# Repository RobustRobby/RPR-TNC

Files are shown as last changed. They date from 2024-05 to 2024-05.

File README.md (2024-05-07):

1. Introduction
The first design of a Teensy-based TNC as a replacement for the SCS Tracker was conceived by Peter Mack and Hans-Peter Helfert, DL6MAA, of SCS. It was based on a stack of a Teensy 4.0 board on top of an audio shield, which was itself on top of a piece of generic PCB for holding some components like a PTT transistor and some LEDs. Soon however, the stack of three PCBs was found to be sub-optimal and the idea of designing a custom PCB came into existence. Peter designed a first version of such a custom PCB, but lacked the time to finish it.

2. The present design
The present design was made by Robert, DM4RW, starting from the initial design of Peter. It is made using KiCad, now in version 7 (note that earlier versions of KiCad cannot open files saved in KiCad 7 format). The idea of the design revolves around putting the SGTL5000 sound chip (the same as used on the audio shield) together will all other components required on a main PCB, no longer requiring the use of an audio shield. Also the Teensy 4.0 micro-controller board finds a place on the main PCB, slightly elevated so as to allow space for components directly under the Teensy.

3. The PCB
The PCB provides space for the SGTL5000 sound chip plus its supporting components, a GPS/GNSS module, connectors such as SMA for an antenna for GPS/GNSS and mini-DIN-6 for connecting a transceiver, signaling LEDs, a 3,5mm RST socket for auxiliary use and a push button to initiate firmware updates. In addition, the design provides for its own power supply allowing power to be provided via pin 5 of the mini-DIN-6 socket as well as PTT via separate PTT line and via the audio-out line (the latter can be activated with a jumper).

4. Specifics of the design
The GNSS module used so far is a Quectel LC76. This is not obligatory, any GPS/GNSS module having the same pin-out and having the same physical size can be used, as long as its (serial) interface to the Teensy runs with 9k6 bps. A simple power back-up arrangement was made, using an over-sized capacitor. This will not allow the GNSS module to continue to run for a long time, but it at least bridges shorter interruptions of the power supply. The LC76 automatically recognizes whether the antenna needs power or not, and deactivates power if there is something wrong the antenna line or the antenna. The Teensy uses an unshielded processor. The external antenna is therefore a requirement and should be put away from the PCB as far as possible, preferably with a free sight to the skies.

The SGTL5000 sound chip finds its place beneath the Teensy. It is the 20 (21) pin version, as opposed to the 32 pin version used on the audio shield. However, the 32 pin version has been discontinued, the 20 pin version not. Note that the chip is very small: it measures 4×4mm with 5 pins on each side, plus a 21st pin on the bottom. There is no means of soldering this by hand, a decent re-flow installation is the least you need to put it into place.

The 3,5mm RST socket is meant to support auxiliary services. As to the date of writing, no firmware supporting such services in a flawless manner has been issued. The RST socket may therefore be omitted, it does not change the behavior of the TNC in any way.

The on-board power supply accepts input voltages between 8 and 28 volts on pin 5 of the mini-DIN-6 socket, and reduces this to 5 volts for the Teensy. It is based on a step-down converter by TI, the TPS54202(H). It is important to note that this converter comes in two flavors, with the H at the end and without. The only difference is the “enable voltage”. The one needs a high voltage, the other a low. For the H version, resistor R13 must be omitted, otherwise the converter won’t start. For the flavor without the H, resistor R13 has to be on the board. Simple measures were taken to prevent current flowing in an uncontrolled manner from computer to external power supply or vice versa in case the Teensy is connected to USB AND external power. However, for that to work, the Teensy must be slightly modified in that the trace connecting the power coming from the USB to the main 5v rail on the Teensy is interrupted (see the Teensy documentation that comes with every Teensy). It is then bridged by a diode that is on the PCB. If you do not need an external power supply, all components related to the power supply can be safely omitted. In that case, powering the TNC can only be done via USB connected to the Teensy.

5. About the files
You’ll find the KiCad files which you can open with the freely available KiCad. At least version 7 should be used, or higher. But not lower, that won’t work. You’ll find Gerber files with which the PCBs can be produced. Furthermore there is a BOM (bill of materials) and P&P (pick-and-placement) files. These were generated to have the board produced by JLCPCB and in addition to that, have all SMD components soldered on the board by JLCPCB. Only the GNSS module and wired components must then be soldered in order to get a fully charged RPR TNC. However, you can choose any other service provider that does the same, although in that case you’d be surely advised to regenerate all files according to the instructions of that service provider. Also with JLCPCB it pays off to check whether their requirements have changed and if so, regenerate all files.

Robert, DM4RW (Meersburg, 07/05/2024)

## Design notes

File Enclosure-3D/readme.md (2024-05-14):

About the enclosures

These enclosures were designed by Oliver, DL4KA. You'll find two versions, one for use without a display and one for use with. The enclosures consist of various parts, notably a main body and two front panels for the rear and the back. For the version with display, there is also a transparent window, which protects the LCD screen.

You can print these items yourself or have them printed at some facility, depending on your preference.

For the enclosure without screen, you can also have alumimium front panels. These you'll find in the main directory under "covers" and are actually KiCad files. You can have these produced at some PCB producing facility that can produce PCBs made of aluminium.

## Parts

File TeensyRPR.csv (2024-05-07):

Source: | C:\Users\rober\OneDrive\Documents\KiCAD\TeensyRPRv3r3\TeensyRPR.kicad_sch
Date: | 02/12/2023 18:50:19
Tool: | Eeschema 7.0.7
Generator: | C:\Program Files\KiCad\7.0\bin\scripting\plugins/bom_csv_grouped_by_value_with_fp.py
Component Count: | 70
Ref | Qnty | Value | Cmp name | Footprint | Description | Vendor | DNP
C1 | 1 | 470uF | CP_Small-Device | Capacitor_SMD:CP_Elec_6.3x7.7
C2 | 1 | 100nF | C_Small | Capacitor_SMD:C_0402_1005Metric | Unpolarized capacitor, small symbol
C4, C7, C9 | 3 | 2µ2 | C_Small | Capacitor_SMD:C_1206_3216Metric | Unpolarized capacitor, small symbol
C5, C6, C8, C16, C18, C19 | 6 | 100n | C_Small | Capacitor_SMD:C_0402_1005Metric | Unpolarized capacitor, small symbol
C10 | 1 | 150n | C_Small | Capacitor_SMD:C_0805_2012Metric | Unpolarized capacitor, small symbol
C11, C12 | 2 | 1µ | C_Small | Capacitor_SMD:C_0805_2012Metric | Unpolarized capacitor, small symbol
C13, C23, C24 | 3 | 10n | C_Small | Capacitor_SMD:C_0402_1005Metric | Unpolarized capacitor, small symbol
C15, C17 | 2 | 10µ | C_Small | Capacitor_SMD:C_0805_2012Metric | Unpolarized capacitor, small symbol
C20, C21 | 2 | 22µ | C_Small | Capacitor_SMD:C_0603_1608Metric | Unpolarized capacitor, small symbol
C22 | 1 | 75pF | C_Small | Capacitor_SMD:C_0603_1608Metric | Unpolarized capacitor, small symbol
D1, D6, D9 | 3 | D_Schottky | D_Schottky | Diode_SMD:D_SOD-123 | Schottky diode
D2, D3 | 2 | LED_RG_ACA | LED_Dual_ACA-Device | LED_THT:LED_D3.0mm-3
D4 | 1 | LED_G | LED | LED_THT:LED_D3.0mm | Light emitting diode
D5 | 1 | LED_RB_ACA | LED_Dual_ACA-Device | LED_THT:LED_D3.0mm-3
D7, D8 | 2 | TVS_5v | TVS_SOD323-TeensyRPR | Diode_SMD:D_SOD-323
D10, D11 | 2 | 1N4148WS | 1N4148WS | Diode_SMD:D_SOD-323 | 75V 0.15A Fast switching Diode, SOD-323
J1 | 1 | AudioPlug3 | AudioPlug3-Connector | Connector_Audio:Jack_3.5mm_Switronic_ST-005-G_horizontal
J2 | 1 | Mini-DIN-6 | Mini-DIN-6 | TeensyRPR:Mini_DIN_6_TE_Connectivity | 6-pin Mini-DIN connector
J3 | 1 | Bluetooth | Conn_01x06 | Connector_PinHeader_2.54mm:PinHeader_1x06_P2.54mm_Vertical | Generic connector, single row, 01x06, script generated (kicad-library-utils/schlib/autogen/connector/)
J5 | 1 | SMA | Conn_Coaxial | Connector_Coaxial:SMA_Molex_73251-2200_Horizontal | coaxial connector (BNC, SMA, SMB, SMC, Cinch/RCA, LEMO, ...)
J6 | 1 | Display (option) | Conn_01x09 | Connector_PinHeader_2.54mm:PinHeader_1x09_P2.54mm_Vertical | Generic connector, single row, 01x09, script generated (kicad-library-utils/schlib/autogen/connector/)
L1 | 1 | 470µ | L_Small | Inductor_SMD:L_1210_3225Metric | Inductor, small symbol
L2 | 1 | 15uH | L_Core_Ferrite-Device | Inductor_SMD:L_Taiyo-Yuden_MD-3030
L3 | 1 | 56nH | L_Small | Inductor_SMD:L_0402_1005Metric | Inductor, small symbol
Q1, Q2 | 2 | 2N7002 | 2N7002 | Package_TO_SOT_SMD:SOT-23 | 0.115A Id, 60V Vds, N-Channel MOSFET, SOT-23
R1, R21 | 2 | 4k7 | R | Resistor_SMD:R_0603_1608Metric | Resistor
R2, R19 | 2 | 100 | R | Resistor_SMD:R_0603_1608Metric | Resistor
R3, R4 | 2 | 2k2 | R | Resistor_SMD:R_0603_1608Metric | Resistor
R5, R7, R9, R11, R20 | 5 | 1k | R | Resistor_SMD:R_0603_1608Metric | Resistor
R6 | 1 | 330 | R | Resistor_SMD:R_0603_1608Metric | Resistor
R8, R10 | 2 | 10k | R | Resistor_SMD:R_0603_1608Metric | Resistor
R12 | 1 | 511k | R | Resistor_SMD:R_0603_1608Metric | Resistor
R13 | 1 | 105k | R | Resistor_SMD:R_0603_1608Metric | Resistor
R14 | 1 | 49.9 | R | Resistor_SMD:R_0603_1608Metric | Resistor
R15 | 1 | 100k | R | Resistor_SMD:R_0603_1608Metric | Resistor
R16 | 1 | 13.3k | R | Resistor_SMD:R_0603_1608Metric | Resistor
R17 | 1 | 33k | R | Resistor_THT:R_Axial_DIN0204_L3.6mm_D1.6mm_P2.54mm_Vertical | Resistor
R18 | 1 | 10 | R | Resistor_SMD:R_2010_5025Metric | Resistor
SW1 | 1 | SW_Push | SW_Push | Button_Switch_THT:SW_Tactile_SPST_Angled_PTS645Vx31-2LFS | Push button switch, generic, two pins
U1 | 1 | L70-R | L70-R | RF_GPS:Quectel_L70-R | Quectel GPS Module
U2 | 1 | AP2120N-1.8TRG1 | MCP1703A-1802_SOT23-Regulator_Linear | Package_TO_SOT_SMD:SOT-23
U3 | 1 | SGTL5000XNLA3 | SGTL5000XNAA3-Audio-TeensyRPR-TeensyRPR-rescue | TeensyRPR:SGTL5000-QFN-20-1EP_3x3mm_P0.4mm_ThermalVias
U4 | 1 | Teensy4.0 | Teensy4.0-TeensyRPR | TeensyRPR:Teensy40-DIP-28_W15.24mm
U6 | 1 | TPS54202DDC | TPS54202DDC | Package_TO_SOT_SMD:SOT-23-6 | 2A, 4.5 to 28V Input, EMI Friendly integrated switch synchronous step-down regulator, pulse-skipping, SOT-23-6

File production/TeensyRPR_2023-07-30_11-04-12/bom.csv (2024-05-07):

Designator | Footprint | Quantity | Value | LCSC Part #
C1 | CP_Elec_6.3x7.7 | 1 | 470uF | C114446
C10 | 805 | 1 | 150n | C307539
C11, C12 | 805 | 2 | 1µ | C28323
C13, C23, C24 | 402 | 3 | 10n | C15195
C15, C17 | 805 | 2 | 10µ | C15850
C16, C18, C19, C5, C6, C8 | 402 | 6 | 100n | C307331
C2 | 402 | 1 | 100nF | C307331
C20, C21 | 603 | 2 | 22µ | C2991805
C22 | 603 | 1 | 75pF | C282074
C4, C7, C9 | 1206 | 3 | 2µ2 | C50254
D1, D6, D9 | D_SOD-123 | 3 | D_Schottky | C8598
D10, D11 | D_SOD-323 | 2 | 1N4148WS | C108805
D7, D8 | D_SOD-323 | 2 | TVS_5v | C170167
L1 | 1210 | 1 | 470µ | C295109
L2 | L_Taiyo-Yuden_MD-3030 | 1 | 15uH | C222856
L3 | 402 | 1 | 56nH | C27143
Q1 | SOT-23 | 1 | 2N7002 | C65189
R1 | 603 | 1 | 4k7 | C23162
R10, R8 | 603 | 2 | 10k | C23179
R11, R5, R7, R9 | 603 | 4 | 470 | C23179
R12 | 603 | 1 | 511k | C101089
R13 | 603 | 1 | 105k | C100713
R14 | 603 | 1 | 49.9 | C114625
R15 | 603 | 1 | 100k | C465461
R16 | 603 | 1 | 13.3k | C234280
R17 | 603 | 1 | 33k | C4216
R18 | 2010 | 1 | 10 | C458682
R19, R2 | 603 | 2 | 100 | C22775
R3, R4 | 603 | 2 | 2k2 | C4190
R6 | 603 | 1 | 330 | C23138
U1 | Quectel_L70-R | 1 | L70-R | C2916232
U2 | SOT-23 | 1 | AP2120N-1.8TRG1 | C460317
U3 | SGTL5000-QFN-20-1EP_3x3mm_P0.4mm_ThermalVias | 1 | SGTL5000XNLA3 | C2651833
U6 | SOT-23-6 | 1 | TPS54202DDC | C191884

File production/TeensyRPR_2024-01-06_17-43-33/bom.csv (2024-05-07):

Designator | Footprint | Quantity | Value | LCSC Part #
C1 | CP_Elec_6.3x7.7 | 1 | 470uF | C114446
C10 | 0805 | 1 | 150n | C113852
C11, C12 | 0805 | 2 | 1µ | C28323
C13, C23, C24 | 0402 | 3 | 10n | C15195
C15, C17 | 0805 | 2 | 10µ | C15850
C16, C18, C19, C2, C5, C6, C8 | 0402 | 7 | 100n | C307331
C20, C21 | 0603 | 2 | 22µ | C2992620
C22 | 0603 | 1 | 75pF | C282074
C4, C7, C9 | 1206 | 3 | 2µ2 | C50254
D1, D6, D9 | D_SOD-123 | 3 | D_Schottky | C8598
D10, D11 | D_SOD-323 | 2 | 1N4148WS | C108805
D7, D8 | D_SOD-323 | 2 | TVS_5v | C85200
L1 | 1210 | 1 | 470µ | C295109
L2 | L_Taiyo-Yuden_MD-3030 | 1 | 15uH | C222856
L3 | 0402 | 1 | 56nH | C27143
Q1, Q2 | SOT-23 | 2 | 2N7002 | C916396
R1, R21 | 0603 | 2 | 4k7 | C23162
R10, R8 | 0603 | 2 | 10k | C23179
R11, R20, R5, R7, R9 | 0603 | 5 | 1k | C2784879
R12 | 0603 | 1 | 511k | C101089
R13 | 0603 | 1 | 105k | C141685
R14 | 0603 | 1 | 49.9 | C114625
R15 | 0603 | 1 | 100k | C465461
R16 | 0603 | 1 | 13.3k | C234280
R18 | 2010 | 1 | 10 | C458682
R19, R2 | 0603 | 2 | 100 | C22775
R3, R4 | 0603 | 2 | 2k2 | C4190
R6 | 0603 | 1 | 330 | C23138
U1 | Quectel_L70-R | 1 | L70-R | C2916232
U2 | SOT-23 | 1 | AP2120N-1.8TRG1 | C460317
U3 | SGTL5000-QFN-20-1EP_3x3mm_P0.4mm_ThermalVias | 1 | SGTL5000XNLA3 | C2651833
U6 | SOT-23-6 | 1 | TPS54202DDC | C191884

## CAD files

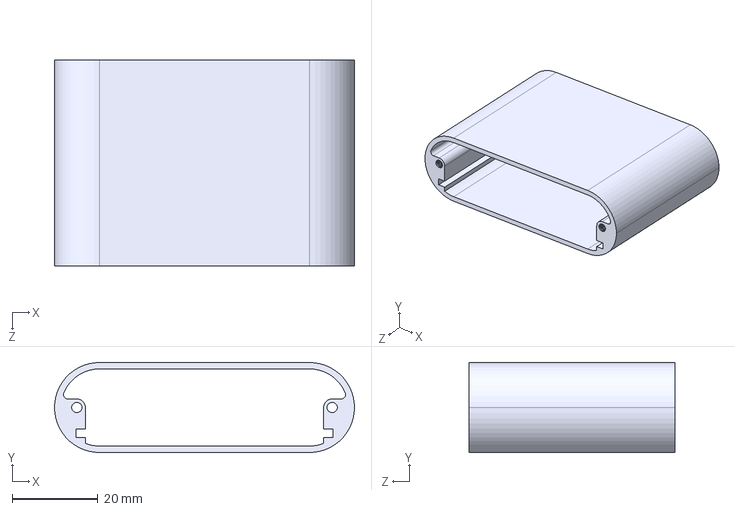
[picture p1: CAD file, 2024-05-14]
Enclosure-3D/shell.STEP
70.0 x 21.0 x 48.0 mm

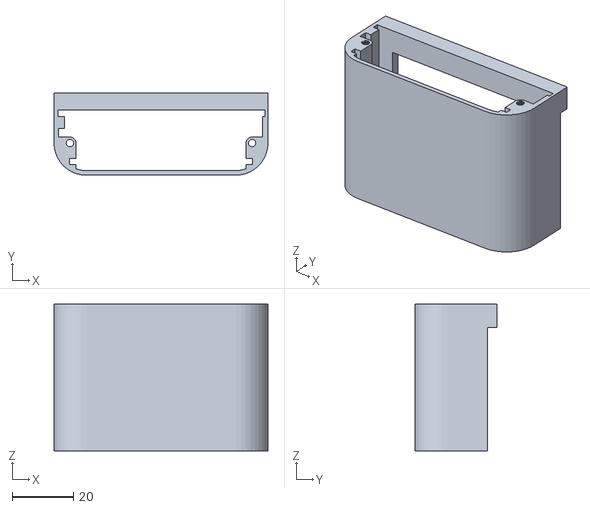
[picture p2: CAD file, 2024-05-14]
Enclosure-3D/withDisplay/shell.STL
70.0 x 27.0 x 48.0

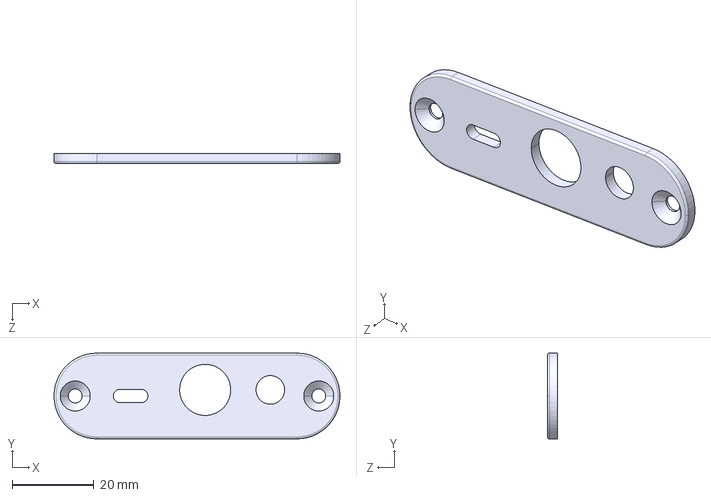
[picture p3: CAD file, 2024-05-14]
Enclosure-3D/rear_plate.STEP
70.0 x 21.0 x 2.50 mm

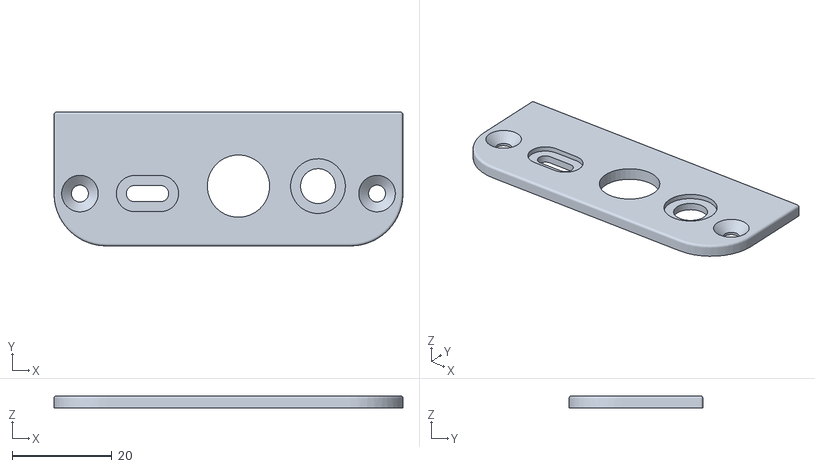
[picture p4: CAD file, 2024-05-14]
Enclosure-3D/withDisplay/rear_plate.STL
70.0 x 26.8 x 2.50

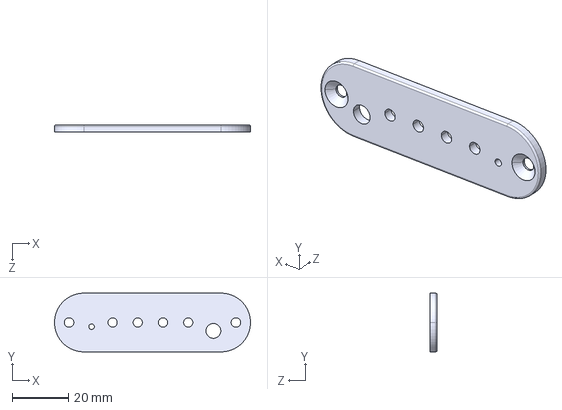
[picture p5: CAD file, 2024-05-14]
Enclosure-3D/front_plate.STEP
70.0 x 21.0 x 2.50 mm

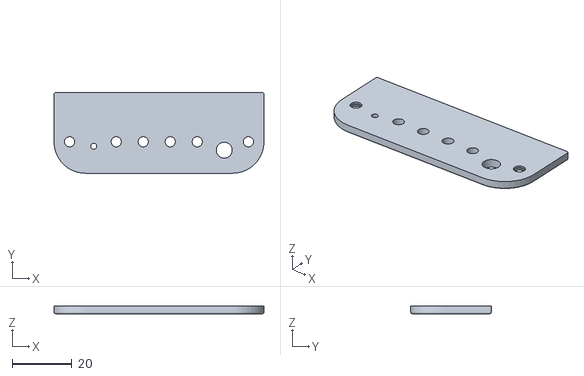
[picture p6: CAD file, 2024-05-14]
Enclosure-3D/withDisplay/front_plate.STL
70.0 x 26.8 x 2.50

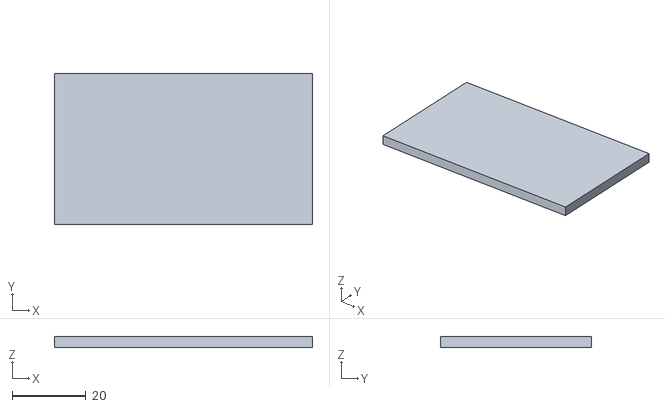
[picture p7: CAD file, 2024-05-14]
Enclosure-3D/withDisplay/PMMA-window.STL
70.0 x 41.0 x 3.00

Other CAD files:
Enclosure-3D/front_plate.STL
Enclosure-3D/rear_plate.STL
Enclosure-3D/shell.STL

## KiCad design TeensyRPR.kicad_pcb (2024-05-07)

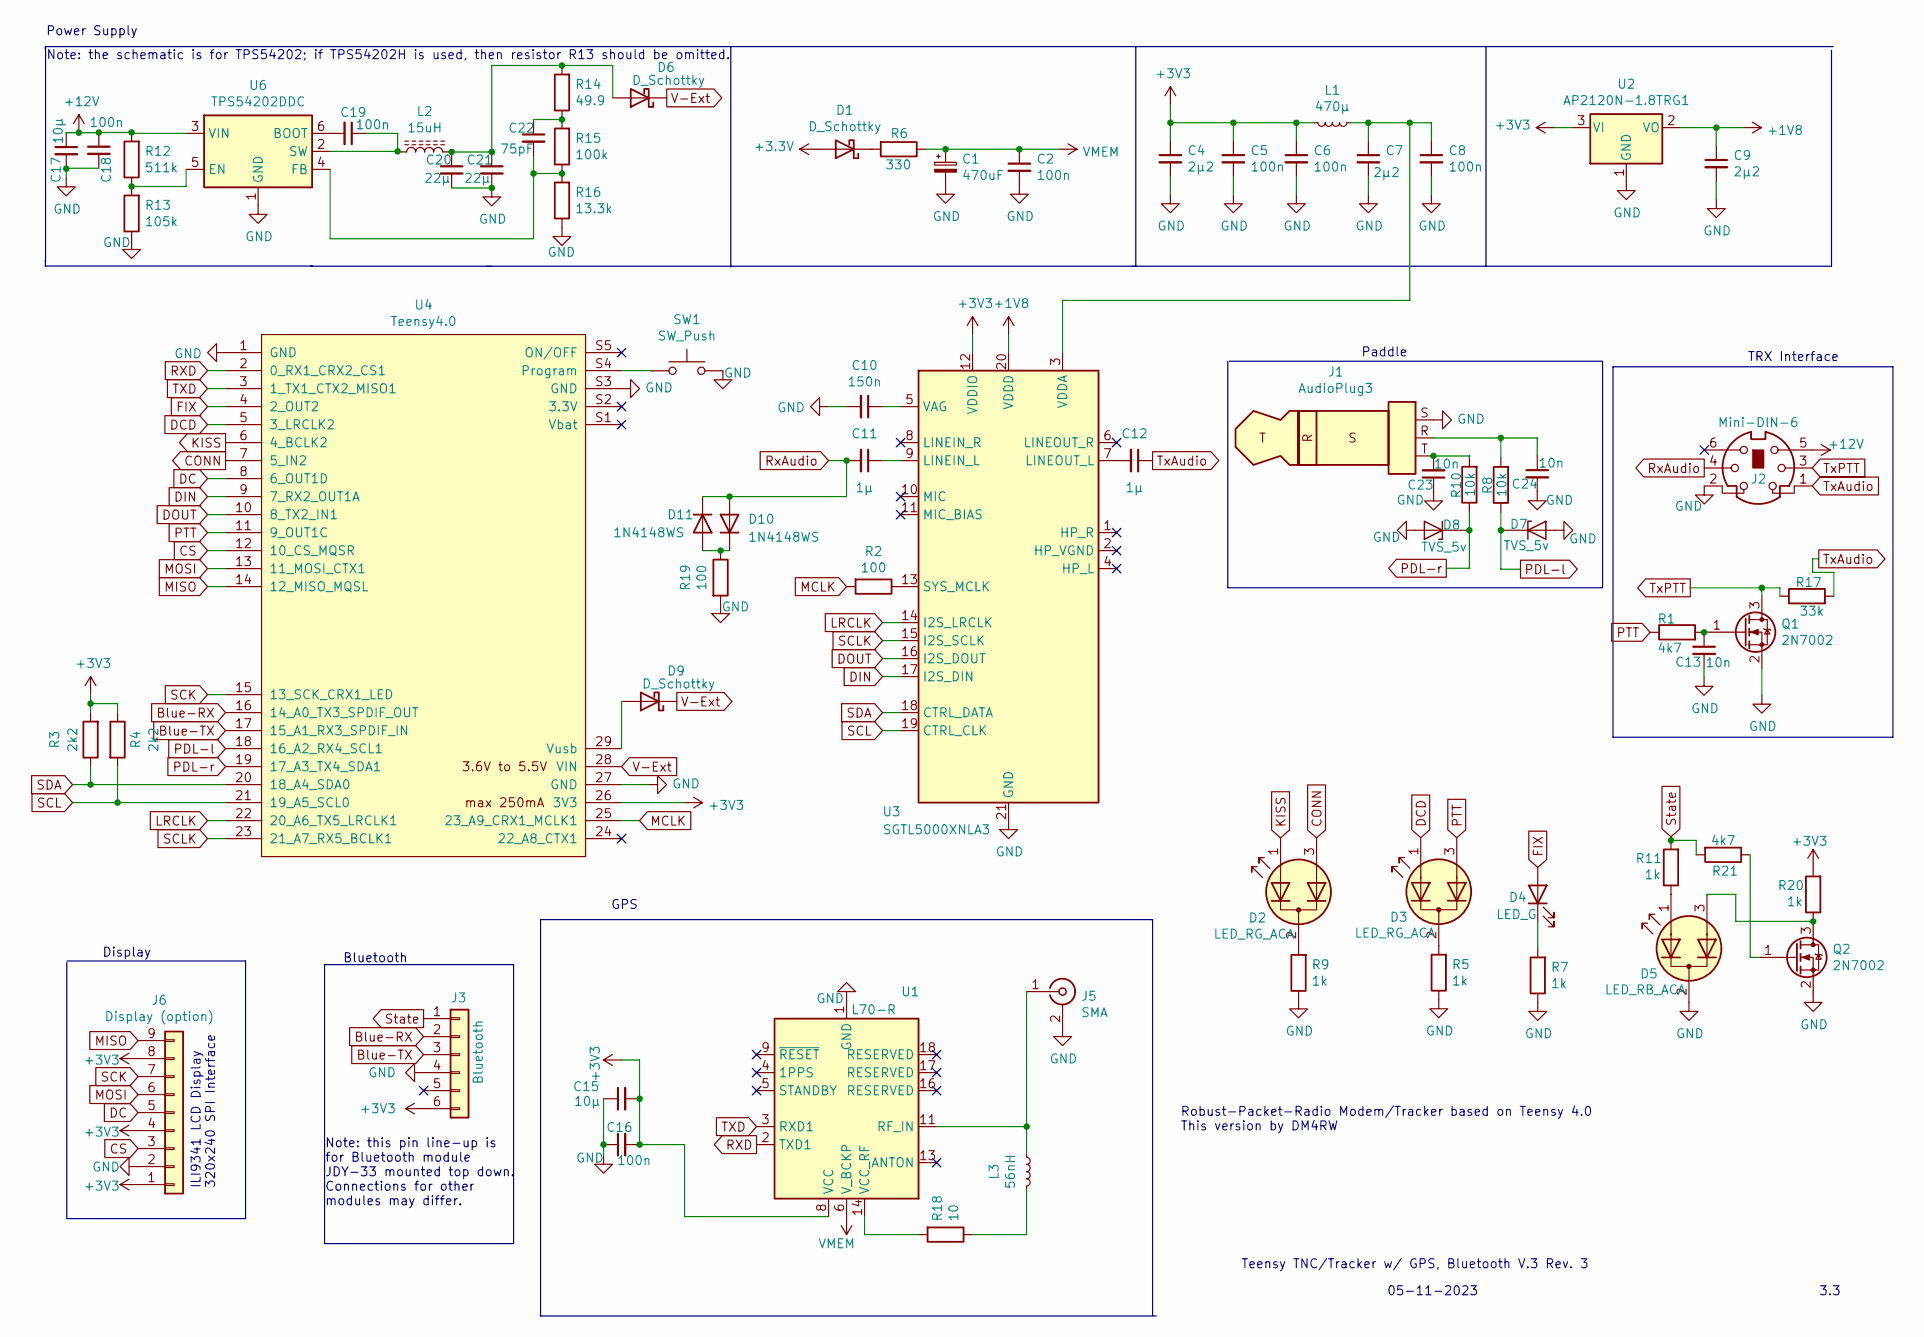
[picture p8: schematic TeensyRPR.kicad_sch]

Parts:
C1: 470uF; CP_Elec_6.3x7.7; LCSC C114446
C2, C5, C6, C8, C16, C18, C19: 100n; C_0402_1005Metric; LCSC C307331
C4, C7, C9: 2µ2; C_1206_3216Metric; LCSC C50254
C10: 150n; C_0805_2012Metric; LCSC C307539
C11, C12: 1µ; C_0805_2012Metric; LCSC C28323
C13, C23, C24: 10n; C_0402_1005Metric; LCSC C15195
C15, C17: 10µ; C_0805_2012Metric; LCSC C15850
C20, C21: 22µ; C_0603_1608Metric; LCSC C2992620
C22: 75pF; C_0603_1608Metric; LCSC C282074
D1, D6, D9: D_Schottky; D_SOD-123; LCSC C8598
D2, D3: LED_RG_ACA; LED_D3.0mm-3
D4: LED_G; LED_D3.0mm
D5: LED_RB_ACA; LED_D3.0mm-3
D7, D8: TVS_5v; D_SOD-323; LCSC C85200
D10, D11: 1N4148WS; D_SOD-323; LCSC C108805
J1: AudioPlug3; Jack_3.5mm_Switronic_ST-005-G_horizontal
J2: Mini-DIN-6; Mini_DIN_6_TE_Connectivity
J3: Bluetooth; PinHeader_1x06_P2.54mm_Vertical
J5: SMA; SMA_Molex_73251-2200_Horizontal
J6: Display (option); PinHeader_1x09_P2.54mm_Vertical
L1: 470µ; L_1210_3225Metric; LCSC C295109
L2: 15uH; L_Taiyo-Yuden_MD-3030; LCSC C222856
L3: 56nH; L_0402_1005Metric; LCSC C27143
Q1, Q2: 2N7002; SOT-23; LCSC C916396
R1, R21: 4k7; R_0603_1608Metric; LCSC C23162
R2, R19: 100; R_0603_1608Metric; LCSC C22775
R3, R4: 2k2; R_0603_1608Metric; LCSC C4190
R5, R7, R9, R11, R20: 1k; R_0603_1608Metric; LCSC C253329
R6: 330; R_0603_1608Metric; LCSC C23138
R8, R10: 10k; R_0603_1608Metric; LCSC C23179
R12: 511k; R_0603_1608Metric; LCSC C101089
R13: 105k; R_0603_1608Metric; LCSC C141685
R14: 49.9; R_0603_1608Metric; LCSC C114625
R15: 100k; R_0603_1608Metric; LCSC C465461
R16: 13.3k; R_0603_1608Metric; LCSC C234280
R17: 33k; R_Axial_DIN0204_L3.6mm_D1.6mm_P2.54mm_Vertical
R18: 10; R_2010_5025Metric; LCSC C458682
SW1: SW_Push; SW_Tactile_SPST_Angled_PTS645Vx31-2LFS
U1: L70-R; Quectel_L70-R; LCSC C2916232
U2: AP2120N-1.8TRG1; SOT-23; LCSC C460317
U3: SGTL5000XNLA3; SGTL5000-QFN-20-1EP_3x3mm_P0.4mm_ThermalVias; LCSC C2651833
U4: Teensy4.0; Teensy40-DIP-28_W15.24mm
U6: TPS54202DDC; SOT-23-6; LCSC C191884

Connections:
+1V8: C9.1, U2.2 (VO), U3.20 (VDDD)
+12V: C17.1, C18.1, J2.5, R12.2, U6.3 (VIN)
Blue-RX: J3.2, U4.16 (14_A0_TX3_SPDIF_OUT)
Blue-TX: J3.3, U4.17 (15_A1_RX3_SPDIF_IN)
CONN: D2.3 (A2), U4.7 (5_IN2)
CS: J6.3, U4.12 (10_CS_MQSR)
DC: J6.5, U4.8 (6_OUT1D)
DCD: D3.1 (A1), U4.5 (3_LRCLK2)
DIN: U3.17 (I2S_DIN), U4.9 (7_RX2_OUT1A)
DOUT: U3.16 (I2S_DOUT), U4.10 (8_TX2_IN1)
FIX: D4.2 (A), U4.4 (2_OUT2)
GND: C1.2, C2.2, C4.2, C5.2, C6.2, C7.2, C8.2, C9.2, C10.2, C13.2, C15.1, C16.1, C17.2, C18.2, C20.2, C21.2, C23.1, C24.2, D5.2 (K), D7.2 (A2), D8.2 (A2), J1.S, J2.2, J3.4, J5.2 (Ext), J6.2, Q1.2 (S), Q2.2 (S), R5.1, R7.1, R9.1, R13.1, R16.1, R19.2, SW1.2, U1.1 (GND), U1.10 (GND), U1.12 (GND), U2.1 (GND), U3.21 (GND), U4.1 (GND), U4.27 (GND), U4.S3 (GND), U6.1 (GND)
KISS: D2.1 (A1), U4.6 (4_BCLK2)
LRCLK: U3.14 (I2S_LRCLK), U4.22 (20_A6_TX5_LRCLK1)
MCLK: R2.2, U4.25 (23_A9_CRX1_MCLK1)
MISO: J6.9, U4.14 (12_MISO_MQSL)
MOSI: J6.6, U4.13 (11_MOSI_CTX1)
unnamed: C22.1, R14.1, R15.2
unnamed: C23.2, J1.T, R10.2
unnamed: C24.1, J1.R, R8.2
unnamed: D1.1 (K), R6.2
unnamed: D2.2 (K), R9.2
unnamed: D3.2 (K), R5.2
unnamed: D4.1 (K), R7.2
unnamed: D5.1 (A1), R11.1
unnamed: D5.3 (A2), Q2.3 (D), R20.1
unnamed: C20.1, C21.1, D6.2 (A), L2.2, R14.2
unnamed: D9.2 (A), U4.29 (Vusb)
unnamed: D10.1 (K), D11.2 (A), R19.1
unnamed: J5.1 (In), L3.1, U1.11 (RF_IN)
unnamed: L3.2, R18.1
unnamed: C13.1, Q1.1 (G), R1.2
unnamed: Q2.1 (G), R21.1
unnamed: R18.2, U1.14 (VCC_RF)
unnamed: C11.1, U3.9 (LINEIN_L)
unnamed: C12.2, U3.7 (LINEOUT_L)
unnamed: R2.1, U3.13 (SYS_MCLK)
unnamed: C10.1, U3.5 (VAG)
unnamed: C7.1, C8.1, L1.1, U3.3 (VDDA)
unnamed: SW1.1, U4.S4 (Program)
unnamed: C19.2, U6.6 (BOOT)
unnamed: R12.1, R13.2, U6.5 (EN)
unnamed: C22.2, R15.1, R16.2, U6.4 (FB)
unnamed: C19.1, L2.1, U6.2 (SW)
PDL-l: D7.1 (A1), R8.1, U4.18 (16_A2_RX4_SCL1)
PDL-r: D8.1 (A1), R10.1, U4.19 (17_A3_TX4_SDA1)
PTT: D3.3 (A2), R1.1, U4.11 (9_OUT1C)
RXD: U1.2 (TXD1), U4.2 (0_RX1_CRX2_CS1)
RxAudio: C11.2, D10.2 (A), D11.1 (K), J2.4
SCK: J6.7, U4.15 (13_SCK_CRX1_LED)
SCL: R4.2, U3.19 (CTRL_CLK), U4.21 (19_A5_SCL0)
SCLK: U3.15 (I2S_SCLK), U4.23 (21_A7_RX5_BCLK1)
SDA: R3.1, U3.18 (CTRL_DATA), U4.20 (18_A4_SDA0)
State: J3.1, R11.2, R21.2
TXD: U1.3 (RXD1), U4.3 (1_TX1_CTX2_MISO1)
TxAudio: C12.1, J2.1, R17.2
TxPTT: J2.3, Q1.3 (D), R17.1
V-Ext: D6.1 (K), D9.1 (K), U4.28 (VIN)
VMEM: C1.1, C2.1, R6.1, U1.6 (V_BCKP)

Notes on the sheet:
Bluetooth
Robust-Packet-Radio Modem/Tracker based on Teensy 4.0 This version by DM4RW
ILI9341 LCD Display 320x240 SPI Interface
3.3
Teensy TNC/Tracker w/ GPS, Bluetooth V.3 Rev. 3
Power Supply
05-11-2023
TRX Interface
Display
GPS
Paddle
Note: this pin line-up is for Bluetooth module JDY-33 mounted top down. Connections for other modules may differ.
Note: the schematic is for TPS54202; if TPS54202H is used, then resistor R13 should be omitted.

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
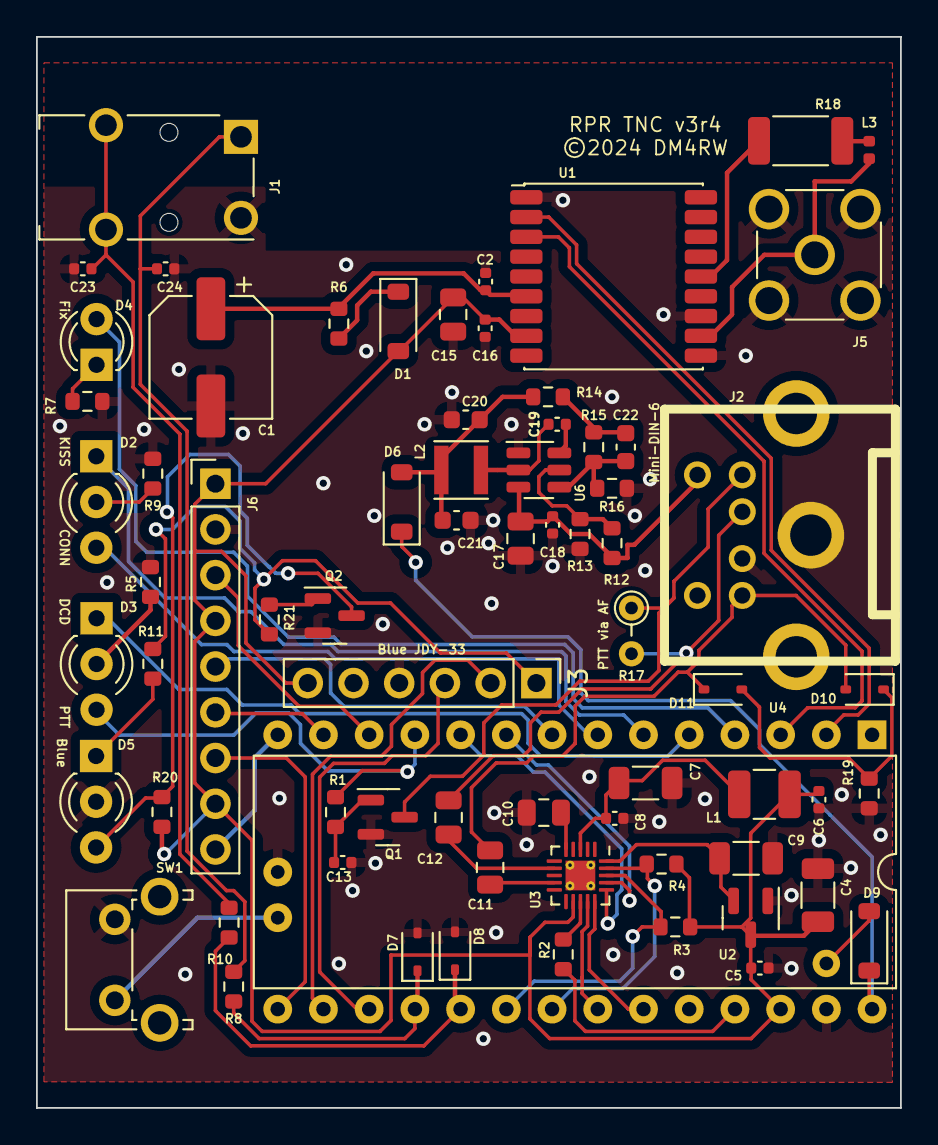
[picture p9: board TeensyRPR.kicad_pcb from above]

Board: 2 copper layers, 48.0 x 59.5 mm, 70 parts (0 on the bottom side), 60 nets.

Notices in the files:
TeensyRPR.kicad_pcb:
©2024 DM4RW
